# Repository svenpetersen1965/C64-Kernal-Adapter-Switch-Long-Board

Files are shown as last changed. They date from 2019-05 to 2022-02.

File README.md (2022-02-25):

# C64-Kernal-Adapter-Switch-Long-Board
This is a Kernal Adapter/Switch for the Commodore C64 long board prior to ASSY250469. 
The kernal selection can be configured with jumpers, a switch or even with a micro controller. +5V are provided on the pin header 
for this purpose.

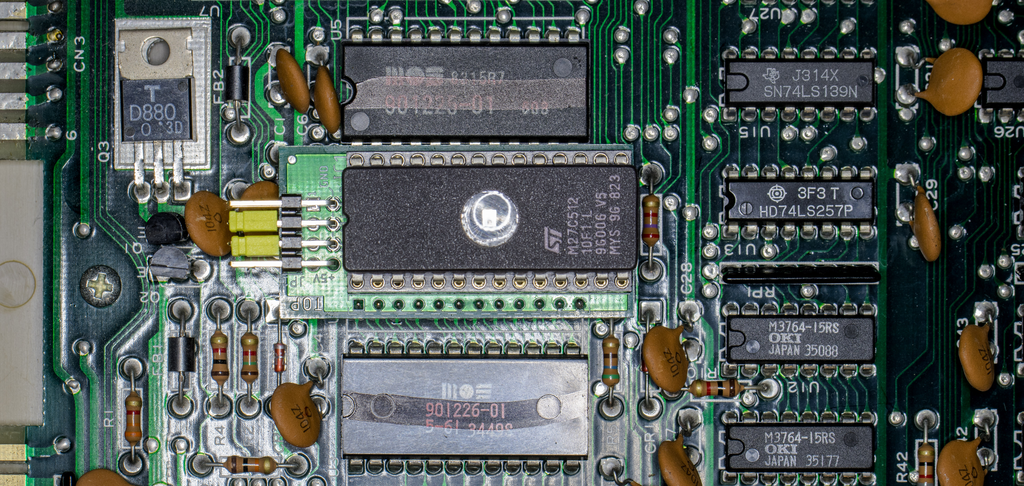
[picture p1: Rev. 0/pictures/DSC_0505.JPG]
C64 kernal adapter/switch for long boards


This adapter is also suitable for the 1541 Floppy Disk ROM.

This development was inspired by Adrian Black's youtube video <a href="https://youtu.be/GPq5xnJRw2w">How-To: C64 Arduino based Restore Key/Four Kernal Switcher/Hard Reset</a>

# Rev. 2
This board revision provides and optional pin header with the address bits A5 and A8 for stereo SID application.

# Calculation of the BOM prices
The component prices of the BOM 0.0 were summed up. The total is 3.81€, which does not include and shipping fees.

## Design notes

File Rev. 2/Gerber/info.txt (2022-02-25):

      
       Board: C64_KernalSw_8k
       Rev.:  2
  
       Files:
       ======
  
       All Gerber files are generated in extended gerber format (RS274X)
       *.TOP        : Film top copper
       *.BOT        :  -"- bottom copper
       *.STC        :  -"- top soldermask 
       *.STS        :  -"- bottom soldermask
       *.PLC        :  -"- silk screen top
       *.PLS        :  -"- silk screen bottom
       *.CRC        :  -"- cream top
       *.DK         : Drills plated Through (Excellon)
       *.NDK        : Drills not plated Through (Excellon)
       *.OUT        : Board outline

       Board Size:
       ===========
       Length     :   45.0 mm
       Width      :   22.0 mm
       Thickness  :   1.6 mm
       Material   :   FR 4
       Copper     :   35 um
       Surface    :   HASL
       
       Remarks:
       ========

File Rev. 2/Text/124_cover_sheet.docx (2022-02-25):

Project Documentation

C64 Kernal Adapter/Switch (Long Board)

Project number: 124

Revision: 2

Date: 14.11.2021

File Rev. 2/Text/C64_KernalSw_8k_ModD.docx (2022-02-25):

C64 Kernal Adapter/Switch (Long Board) Rev. 2

Module Description

# Introduction

The board serves for adapting the KERNAL ROM U4 (type 2364) to a 27C512 (or 27C256, 27C128, 27C64) EPROM. The pin out of both ICs are slightly different and need adaptation. Furthermore, it allows to access (up to 8) different kernals, which can be selected via the pin-header on the module.

This pin-header is connected in a way, that the selection can either be accomplished with standard 2.54mm jumper bridges, DIP-switches, hex-encoding switches or a microcontroller like an Arduino etc.

Signal | Pin | Pin | Signal
A13 | 1 | 2 | GND
A14 | 3 | 4 | GND
A15 | 5 | 6 | GND
+5V | 7 | 8 | +5V

Table 1: Jumper (JP1) for Bank Selection

The +5V pins are to provide supply voltage to a microcontroller.

# Dimensions

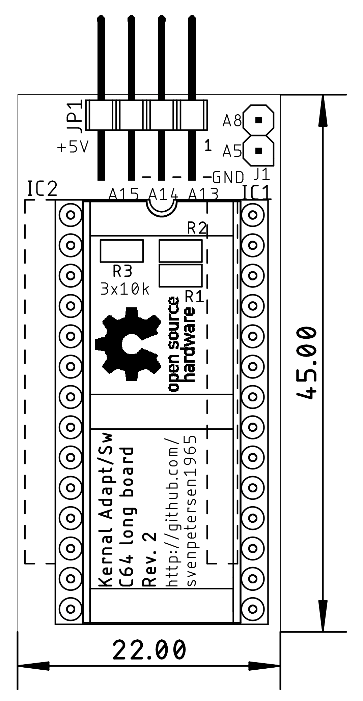
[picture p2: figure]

Figure 1: Kernal Adapter/Switch

# Bank Selection

The desired KERNAL is selected at JP1. For the pinout refer to Table 1. The jumper is installed (vertically) in a way, that it connects the address line with the GND potential.

A15 | A14 | A13 | 8k Block | Addr. Offset
set | set | set | #0 | 0x0000
set | set | open | #1 | 0x2000
set | open | set | #2 | 0x4000
set | open | open | #3 | 0x6000
open | set | set | #4 | 0x8000
open | set | open | #5 | 0xA000
open | open | set | #6 | 0xC000
open | open | open | #7 | 0xE000

Table 2: Selection of EPROM memory blocks

A set jumper corresponds to a LOW level (binary 0), an open jumper to a HIGH level. Do not confuse the C64 memory address and the EPROM memory address. They have the address Bit A0 to A12 in common, but the rest is different. Each of the 8k blocks appears between address $E000 and $FFFF of the C64.

# Sources for KERNAL

The content of the KERNAL ROM can be found here:

http://www.zimmers.net/anonftp/pub/cbm/firmware/computers/c64/index.html (kernal.901227-03.bin (http://www.zimmers.net/anonftp/pub/cbm/firmware/computers/c64/kernal.901227-03.bin))

This file includes the original KERNAL (Rev. 3) and could be loaded to the lowest 8k of the EPROM. In case it is desired to have the original in bank#0. Also Scandinavian KERNAL ROMs can be found at the URL mentioned before or can alternatively be obtained from the Emulator Software VICE (./C64/kernal).

Alternative kernals can be found elsewhere on internet. A reliable source is

https://csdb.dk/

The popular JiffyDOS is still a commercial product and can be acquired for little money from

http://www.go4retro.com/ or

JaffyDOS is a patch for JiffyDOS. The patch program can be obtained from World of Jani:

http://blog.worldofjani.com

# Setting up an EPROM image

Combining the desired ROM (*.bin) files to one programming image works with the software of the programmer. This might a different with different model. Here it is demonstrated using the popular TL866. In case the programmer software does not provide the function, a Hex Editor like HxD will do the job.

The first KERNAL ROM has to be loaded into the buffer like this:

File → Open → Select the BASIC ROM

Use default file load options (Figure 2):

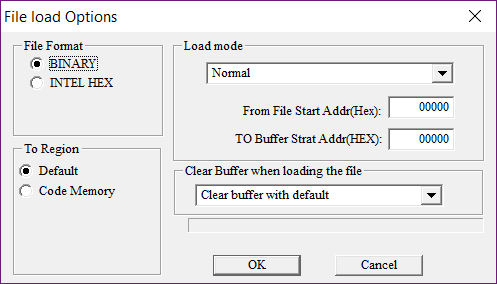
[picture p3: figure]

Figure 2: Default load options, clear buffer with default

Now this Kernal is loaded. It will occupy the addresses 0000 – 1FFF.

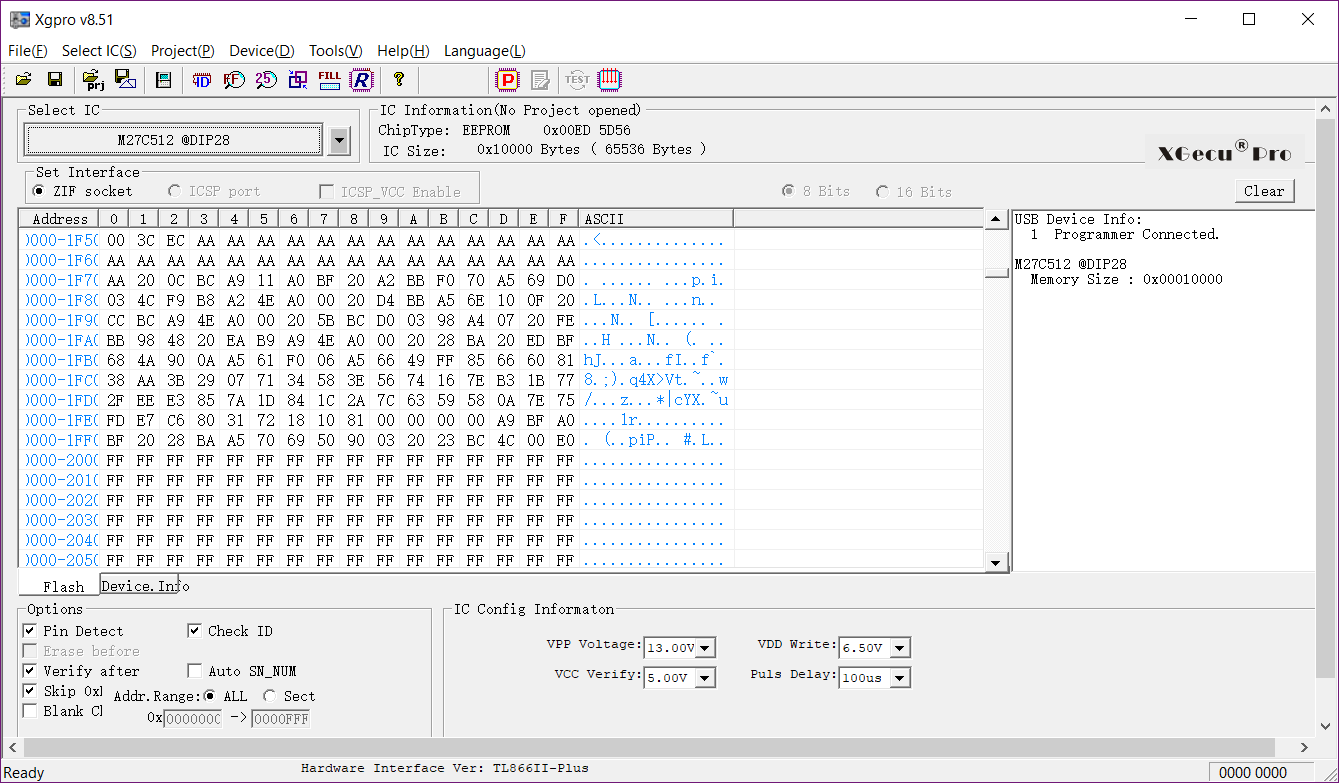
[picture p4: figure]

Figure 3: Buffer content after BASIC was loaded

The buffer above 1FFF is still empty (filled with FF, Figure 3).

The next KERNAL has to be loaded to the next free 8k memory block in the buffer. Please refer to Table 2. Further, it is important, not to clear the buffer. Otherwise, the BASIC will be lost and the EPROM will not work. Refer to Figure 4.

Clear Buffer when loading file is disabled, the address for the first kernal is 2000HEX

Repeat this procedure with the appropriate buffer/EPROM address, until all desired kernals are in the buffer. Store the buffer for later use, insert a blank EPROM and program it. Insert it in the Kernal Adapter/Switch.

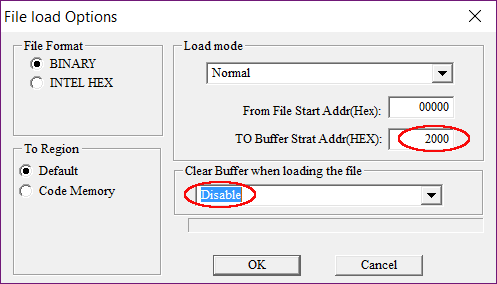
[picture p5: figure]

Figure 4: Load options for the first KERNAL

# Adding more Kernals to an already programmed EPROM

In case the unused 8k memory slots of the EPROM are filled with FF, it is still possible to program additional kernel images without erasing them before. FF is the content of an empty byte in an EPROM. It is possible to alter such a byte to every other byte content. Before the new memory is written, the prior content can be read into the program buffer, then a free 8k slot is determined and the kernel is loaded into that slot. Refer to chapter “Setting up an EPROM image”. Now, the buffer content can be programmed. It is possible to program the complete buffer, the bytes already programmed will (usually) not be corrupted and after programming, the EPROM will verify ok.

# Installation

In some cases, the KERNAL ROM (U4) has to be unsoldered and a socket (preferably round pin precision contacts) has to be installed, before the Kernal Adapter/Switch can be installed on the Long Board. The notch of the EPROM is pointing towards the user port, when installed properly (Figure 5).

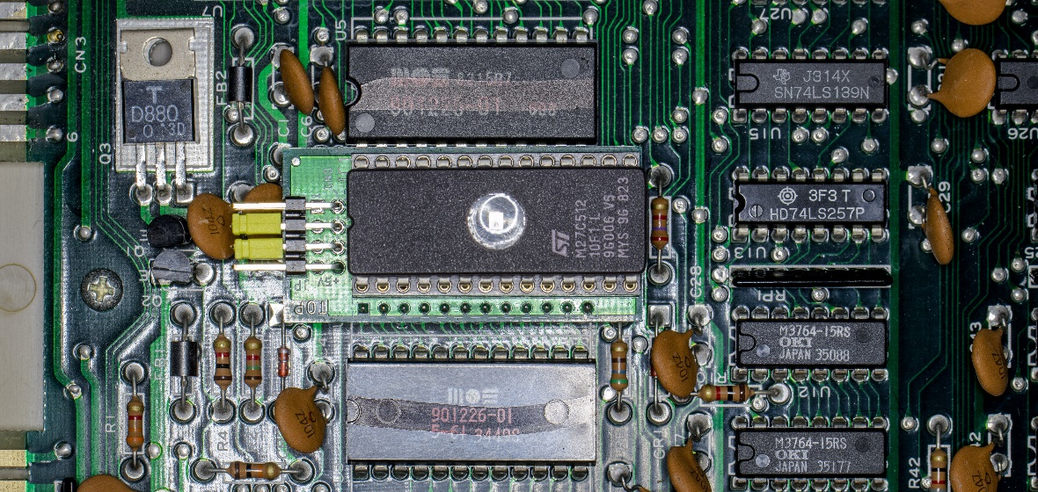
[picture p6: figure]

Figure 5: Installation of the Kernal Adapter/Switch

The capacitor under the board needs to be bent a bit backwards in order not to collide with it.

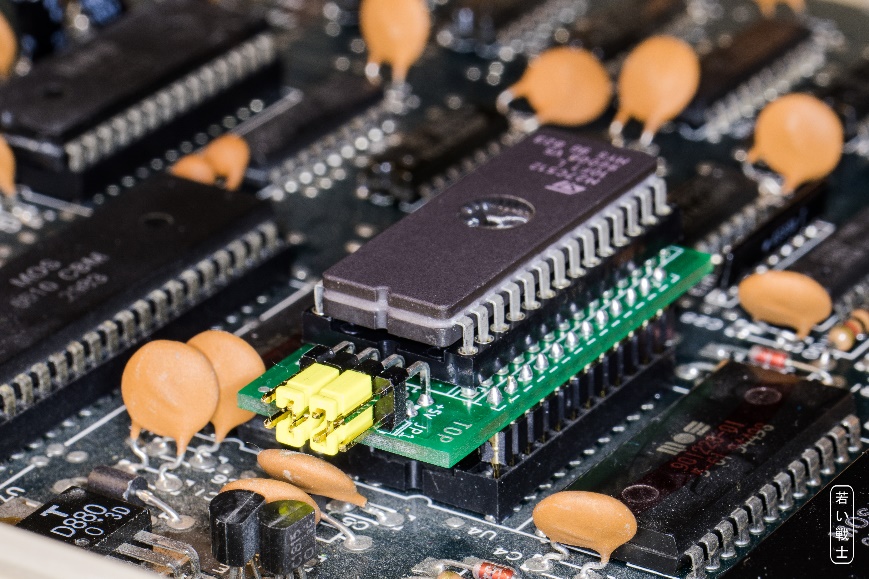
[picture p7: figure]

Figure 6: Parts under the adapter board

# Compatibility of EPROMs

Although a 27C512 type EPROM is recommended, other types of EPROMs can be installed:

EPROM | Size | Capacity
27C64 | 8k | 1x KERNAL
27C128 | 16k | 2x KERNAL
27C256 | 32k | 4x KERNAL
27C512 | 64k | 8x KERNAL

Table 3: Capacity of EPROM types

Those EPROMs are pin compatible, the jumpers, that have no function, due to the size, have to stay open.

EPROM | Size | A15 | A14 | A13
27C512 | 64kx8 | ☑ | ☑ | ☑
27C256 | 32kx8 | open | ☑ | ☑
27C128 | 16kx8 | open | open | ☑
27c64 | 8kx8 | open | open | open

Table 4: Settings per EPROM type

☑: The jumper can be open or closed, depending on the desired selection.

In case Vpp is located at a dedicated pin (pin 1), A15 has no effect anymore. A HIGH level is recommended, the corresponding jumper is open. The /PGM Pin should be set HIGH, this is accomplished by an open jumper for A14. “n.c.” means not connected. Just leave the jumper open for it.

27C64
| 27C128
| | 27C256
| | | 27C512
| | | | SOCKET
Vpp | Vpp | Vpp | A15 | 1 | A15 | VCC | 28 | VCC | VCC | VCC | VCC
A12 | A12 | A12 | A12 | 2 | A12 | A14 | 27 | A14 | A14 | /PGM | /PGM
A7 | A7 | A7 | A7 | 3 | A7 | A13 | 26 | A13 | A13 | A13 | n.c.
A6 | A6 | A6 | A6 | 4 | A6 | A8 | 25 | A8 | A8 | A8 | A8
A5 | A5 | A5 | A5 | 5 | A5 | A9 | 24 | A9 | A9 | A9 | A9
A4 | A4 | A4 | A4 | 6 | A4 | A11 | 23 | A11 | A11 | A11 | A11
A3 | A3 | A3 | A3 | 7 | A3 | /OE | 22 | /G/Vpp | /G | /G | /G
A2 | A2 | A2 | A2 | 8 | A2 | A10 | 21 | A10 | A10 | A10 | A10
A1 | A1 | A1 | A1 | 9 | A1 | GND | 20 | /E | /E | /E | /E
A0 | A0 | A0 | A0 | 10 | A0 | D7 | 19 | D7 | D7 | D7 | D7
D0 | D0 | D0 | D0 | 11 | D0 | D6 | 18 | D6 | D6 | D6 | D6
D1 | D1 | D1 | D1 | 12 | D1 | D5 | 17 | D5 | D5 | D5 | D5
D2 | D2 | D2 | D2 | 13 | D2 | D4 | 16 | D4 | D4 | D4 | D4
GND | GND | GND | GND | 14 | GND | D3 | 15 | D3 | D3 | D3 | D3

Table 5: EPROM pin compatibility

# Startup and Trouble shooting

Before you insert the Kernal Adaptor/Switch into the socket of U4, you should make sure, that there are no fatal failures on it. In the worst case, it will produce a short circuit.

- Check the solder joints on the solder side
- Check the orientation of the socket. The notch is oriented to the side, where the jumper is located
- Make sure, that no jumper is installed horizontally. This could connect GND and VCC, which is a short circuit.
- After inserting the EPROM, check if the notch is at the same side like the notch of the socket. Check all pins are properly seated in the socket and not bent inwards or outwards.

After all these points are correct, nothing really bad can happen to your C64 anymore. If you get a black screen you only have a configuration problem.

- Did you program the EPROM with a proper *.bin file? (*.rom) Maybe check the buffer content of your programmed software again.
- Did you set the address bits A13…A15 correctly? A set (closed) jumper means LOW

# Revision History

## Rev. 0 → Rev. 1

- Solder Pads for the pin header JP1 is ready for solder bridges
- Pin 8 of JP1 is not connected

## Rev. 1 → Rev. 2

- J1 is new and providing A5 and A8 for stereo SID applications

C64_KernalSw_8k_ModD.docx 25.02.2022 09:10 Drafted by Sven Petersen Page 2 of 2 Doc.-No.: 124-6-01-02

C64_KernalSw_8k_ModD.docx 25.02.2022 09:10 Drafted by Sven Petersen Page 1 of 1 Doc.-No.: 124-6-01-01

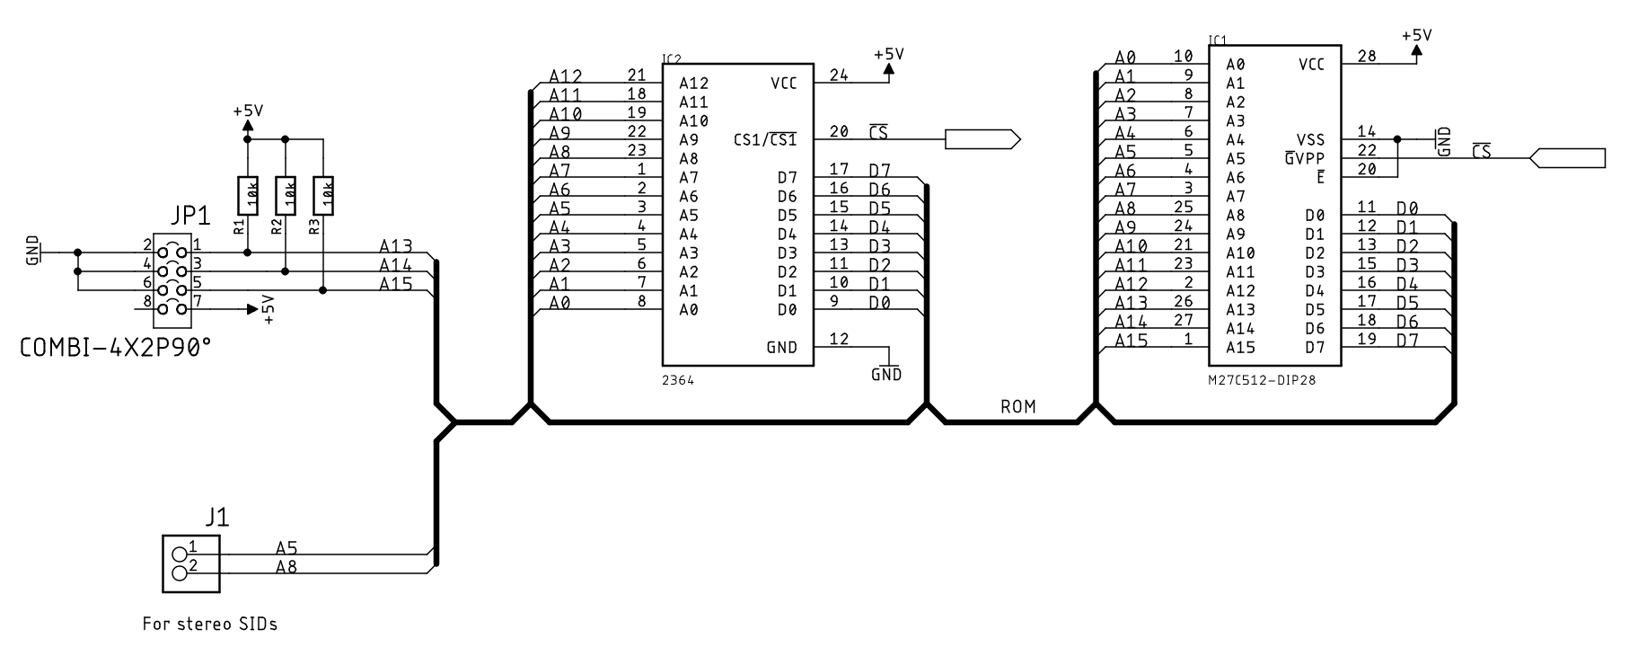
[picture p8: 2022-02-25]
Rev. 2/pictures/C64_KernalSw_8k_v2_sch.png

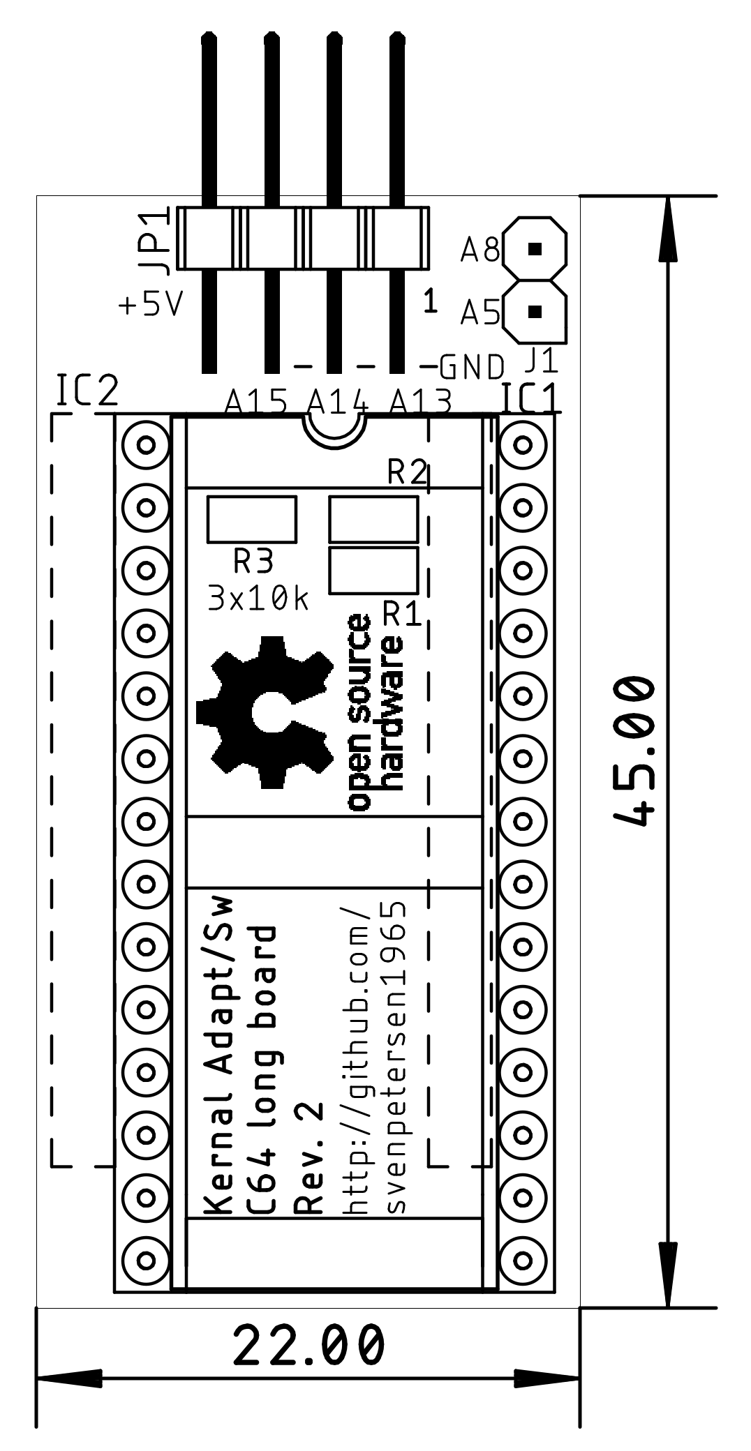
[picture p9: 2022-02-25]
Rev. 2/pictures/C64_KernalSw_8k_v2_dim.png

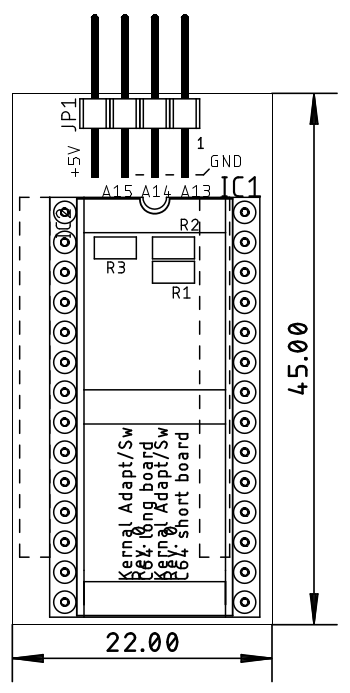
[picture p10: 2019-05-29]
Rev. 1/pictures/C64_KernalSw_8k_v0_dim.png

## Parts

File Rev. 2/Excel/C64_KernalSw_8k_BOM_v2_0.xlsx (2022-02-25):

C64 Kernal Adapter/Switch for lhort boards Rev. 2
Bill of Material Rev. 2.0
Pos. | Qty | Value | Footprint | Ref.-No. | Comment
1 | 1 | 124-2-01-02 | 2 Layer | PCB Rev. 2 | 2 layer, Cu 35µ, HASL, 45mm x 22mm, 1.6mm FR4
2 | 1 | 2x04pin/90° | 2X04_90_SERIES_088 | JP1 | 90° pin header, 2.54mm pitch. E.g. Reichelt MPE 088-2-008
3 | 3 | Jumper | 2.54mm | (JP1) | Jumpers for address selection (in case it is intended to jumper the kenal selection)
4 | 3 | 10k | 0805 | R1, R2, R3 | SMD resistor
5 | 1 | two Pinstrip, precision round pins, cut to 12 pins length | DIL24_SOCKET | IC2 | Precision Round pins mandatory! E.g. Reichelt BKL 10120540 or
 |  |  |  |  | 10PCS Single Row 40Pin 2.54mm Round Male Pin Header machined (https://www.ebay.de/itm/10PCS-Single-Row-40Pin-2-54mm-Round-Male-Pin-Header-machined/281821698031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)
6 | 1 | M27C512 | DIL28-6 | IC1 | EPROM 200ns or faster recommended, alternative sizes: 27C64, 27C128, 27C256 possible
7 | 1 | DIP28 socket | DIL28-6 | (IC1) | Precision round pin is recommended
8 | 1 | Pin header 2p, 2.54mm |  | J1 | standard pin header

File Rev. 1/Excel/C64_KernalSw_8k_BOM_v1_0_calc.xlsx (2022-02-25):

C64 Kernal Adapter/Switch for Short boards Rev. 1
Bill of Material Rev. 1.0
Pos. | Qty | Value | €/ea | € | Comment
1 | 1 | 124-2-01-01 | 1.00 € | 1.00 € | 2 layer, Cu 35µ, HASL, 45mm x 22mm, 1.6mm FR4
2 | 1 | 2x04pin/90° | 0.27 € | 0.27 € | 90° pin header, 2.54mm pitch. E.g. Reichelt MPE 088-2-008
3 | 3 | Jumper | 0.02 € | 0.06 € | Jumpers for address selection (in case it is intended to jumper the kenal selection)
4 | 3 | 10k | 0.02 € | 0.06 € | SMD resistor
5 | 1 | two Pinstrip, precision round pins, cut to 12 pins length | 1.99 € | 1.99 € | Precision Round pins mandatory! E.g. Reichelt BKL 10120540 or
 |  |  |  | 0.00 € | 10PCS Single Row 40Pin 2.54mm Round Male Pin Header machined (https://www.ebay.de/itm/10PCS-Single-Row-40Pin-2-54mm-Round-Male-Pin-Header-machined/281821698031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)
6 | 1 | M27C512 | 0.00 € | 0.00 € | EPROM 200ns or faster recommended, alternative sizes: 27C64, 27C128, 27C256 possible
7 | 1 | DIP28 socket | 0.43 € | 0.43 € | Precision round pin is recommended
8 |  |  | Total | 3.81 €

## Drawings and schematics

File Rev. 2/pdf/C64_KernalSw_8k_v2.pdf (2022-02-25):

# Project Documentation

## C64 Kernal Adapter/Switch (Long Board)

## Project number: 124

## Revision: 2

## Date: 14.11.2021

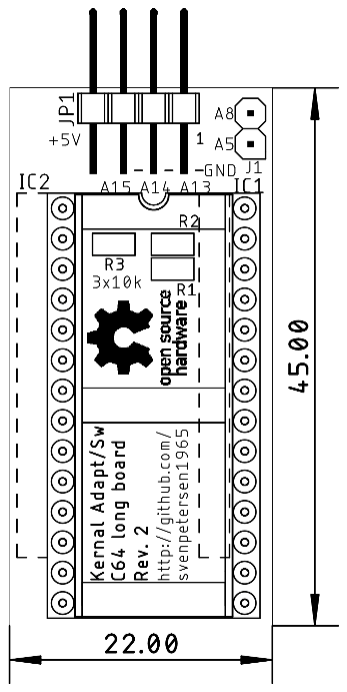
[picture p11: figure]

C64_KernalSw_8k_ModD.docx | | 25.02.2022 09:10
Drafted by Sven Petersen | Page 1 of 6 | Doc.-No.: 124-6-01-02

### C64 Kernal Adapter/Switch (Long Board) Rev. 2

### Module Description

## Introduction

The board serves for adapting the KERNAL ROM U4 (type 2364) to a 27C512 (or 27C256, 27C128, 27C64) EPROM. The pin out of both ICs are slightly different and need adaptation. Furthermore, it allows to access (up to 8) different kernals, which can be selected via the pin-header on the module.

This pin-header is connected in a way, that the selection can either be accomplished with standard 2.54mm jumper bridges, DIP-switches, hex-encoding switches or a microcontroller like an Arduino etc.

Signal Pin | Pin Signal
A13 | 1 | 2 | GND
A14 | 3 | 4 | GND
A15 | 5 | 6 | GND
+5V | 7 | 8 | +5V
Table 1: Jumper (JP1) for Bank Selection

The +5V pins are to provide supply voltage to a microcontroller.

## Dimensions

Figure 1: Kernal Adapter/Switch

## Bank Selection

The desired KERNAL is selected at JP1. For the pinout refer to Table 1. The jumper is installed (vertically) in a way, that it connects the address line with the GND potential.

C64_KernalSw_8k_ModD.docx | | 25.02.2022 09:10
Drafted by Sven Petersen | Page 2 of 6 | Doc.-No.: 124-6-01-02
A15 | A14 | A13 | 8k Block | Addr. Offset
set | set | set | #0 | 0x0000
set | set | open | #1 | 0x2000
set | open | set | #2 | 0x4000
set | open | open | #3 | 0x6000
open | set | set | #4 | 0x8000
open | set | open | #5 | 0xA000
open | open | set | #6 | 0xC000
open | open | open | #7 | 0xE000
Table 2: Selection of EPROM memory blocks

A set jumper corresponds to a LOW level (binary 0), an open jumper to a HIGH level. Do not confuse the C64 memory address and the EPROM memory address. They have the address Bit A0 to A12 in common, but the rest is different. Each of the 8k blocks appears between address $E000 and $FFFF of the C64.

## Sources for KERNAL

The content of the KERNAL ROM can be found here:

http://www.zimmers.net/anonftp/pub/cbm/firmware/computers/c64/index.html (kernal.901227-03.bin) (http://www.zimmers.net/anonftp/pub/cbm/firmware/computers/c64/kernal.901227-03.bin)

This file includes the original KERNAL (Rev. 3) and could be loaded to the lowest 8k of the EPROM. In case it is desired to have the original in bank#0. Also Scandinavian KERNAL ROMs can be found at the URL mentioned before or can alternatively be obtained from the Emulator Software VICE (./C64/kernal).

Alternative kernals can be found elsewhere on internet. A reliable source is

https://csdb.dk/

The popular JiffyDOS is still a commercial product and can be acquired for little money from

http://www.go4retro.com/ or

JaffyDOS is a patch for JiffyDOS. The patch program can be obtained from World of Jani:

http://blog.worldofjani.com

## Setting up an EPROM image

Combining the desired ROM (*.bin) files to one programming image works with the software of the programmer. This might a different with different model. Here it is demonstrated using the popular TL866. In case the programmer software does not provide the function, a Hex Editor like HxD will do the job.

The first KERNAL ROM has to be loaded into the buffer like this:

File → Open → Select the BASIC ROM

Use default file load options (Figure 2):

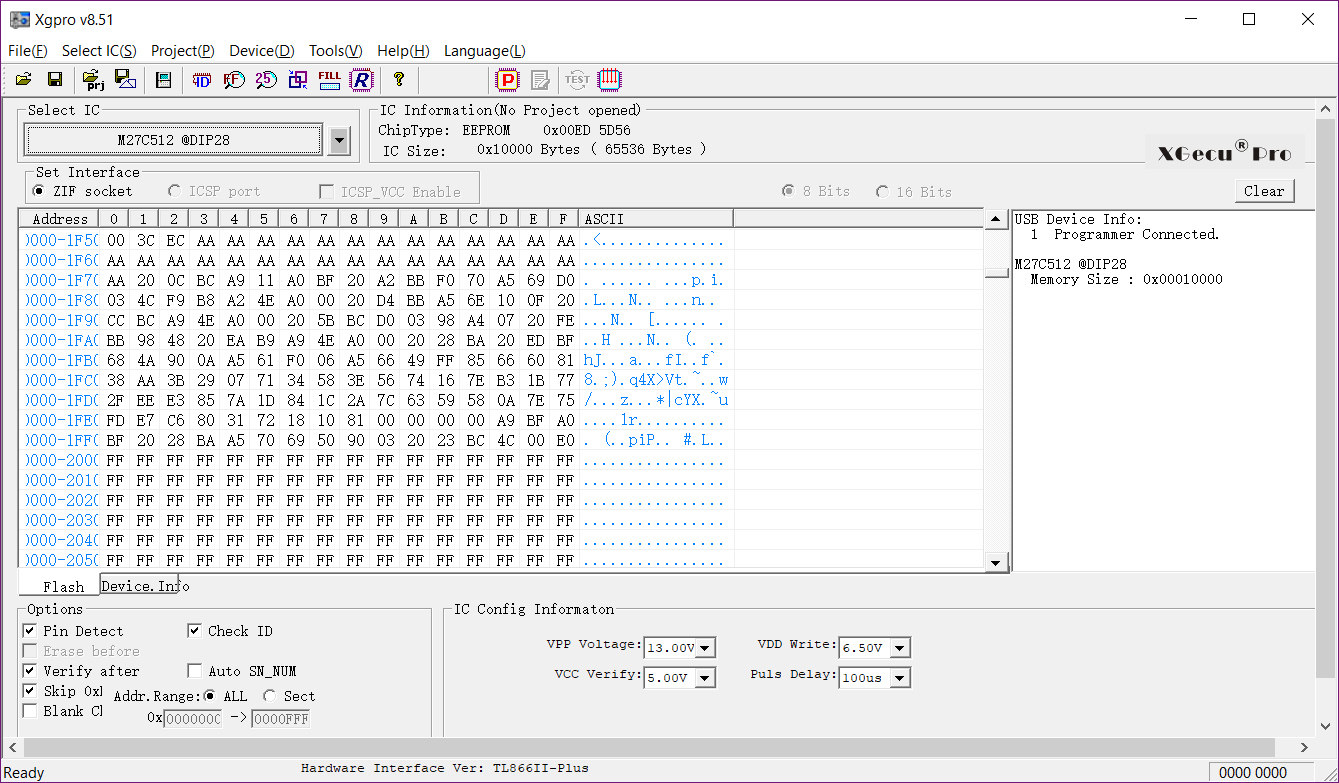
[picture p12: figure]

C64_KernalSw_8k_ModD.docx | | 25.02.2022 09:10
Drafted by Sven Petersen | Page 3 of 6 | Doc.-No.: 124-6-01-02

Figure 2: Default load options, clear buffer with default
Now this Kernal is loaded. It will occupy the addresses 0000 – 1FFF.

Figure 3: Buffer content after BASIC was loaded

The buffer above 1FFF is still empty (filled with FF, Figure 3).

The next KERNAL has to be loaded to the next free 8k memory block in the buffer. Please refer to Table 2. Further, it is important, not to clear the buffer. Otherwise, the BASIC will be lost and the EPROM will not work. Refer to Figure 4.

Clear Buffer when loading file is disabled, the address for the first kernal is 2000HEX

Repeat this procedure with the appropriate buffer/EPROM address, until all desired kernals are in the buffer. Store the buffer for later use, insert a blank EPROM and program it. Insert it in the Kernal Adapter/Switch.

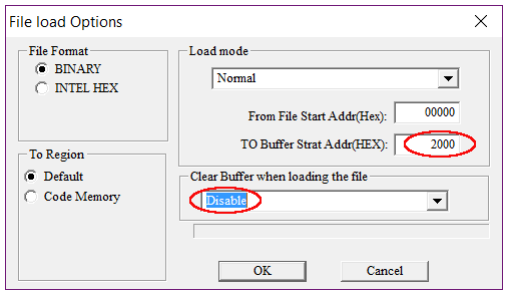
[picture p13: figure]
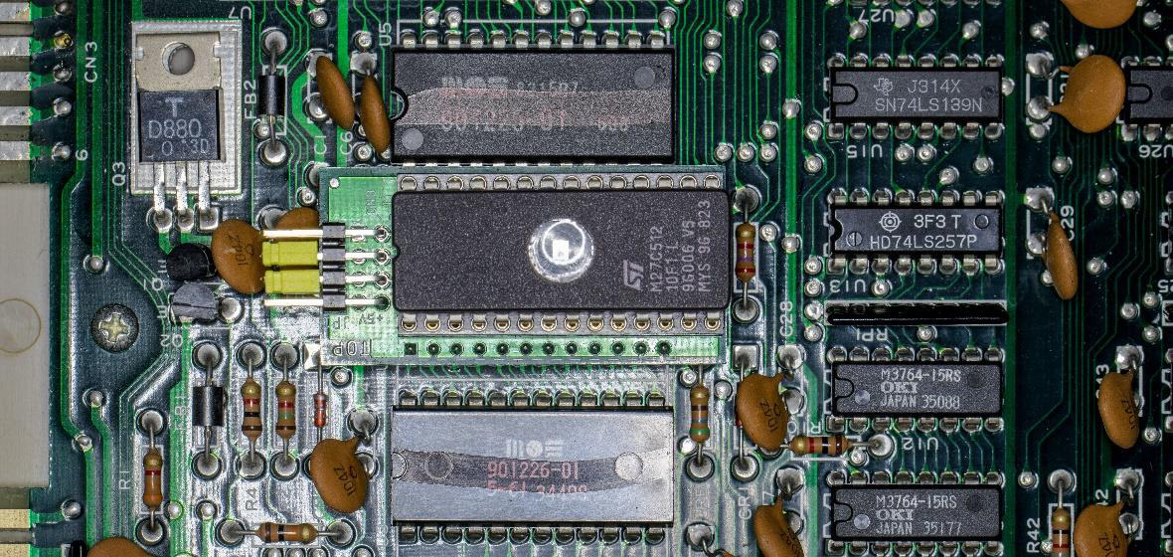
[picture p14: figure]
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

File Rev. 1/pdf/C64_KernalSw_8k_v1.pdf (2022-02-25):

# Project Documentation

## C64 Kernal Adapter/Switch (Long Board)

## Project number: 124

## Revision: 1

## Date: 17.02.2021

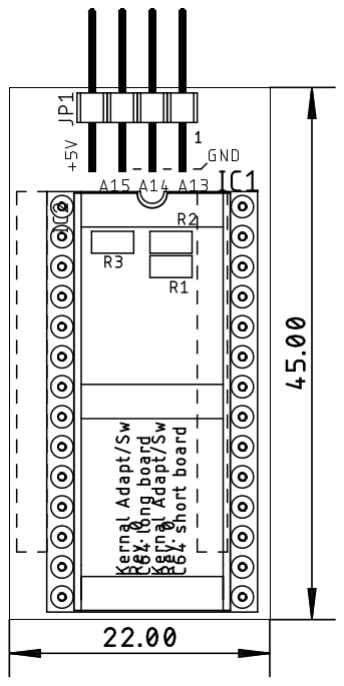
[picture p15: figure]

C64_KernalSw_8k_ModD.docx | | 25.02.2022 08:42
Drafted by Sven Petersen | Page 1 of 6 | Doc.-No.: 124-6-01-01

### C64 Kernal Adapter/Switch (Long Board) Rev. 1

### Module Description

## Introduction

The board serves for adapting the KERNAL ROM U4 (type 2364) to a 27C512 (or 27C256, 27C128, 27C64) EPROM. The pin out of both ICs are slightly different and need adaptation. Furthermore, it allows to access (up to 8) different kernals, which can be selected via the pin-header on the module.

This pin-header is connected in a way, that the selection can either be accomplished with standard 2.54mm jumper bridges, DIP-switches, hex-encoding switches or a microcontroller like an Arduino etc.

Signal Pin | Pin Signal
A13 | 1 | 2 | GND
A14 | 3 | 4 | GND
A15 | 5 | 6 | GND
+5V | 7 | 8 | +5V
Table 1: Jumper (JP1) for Bank Selection

The +5V pins are to provide supply voltage to a microcontroller.

## Dimensions

Figure 1: Kernal Adapter/Switch

## Bank Selection

The desired KERNAL is selected at JP1. For the pinout refer to Table 1. The jumper is installed (vertically) in a way, that it connects the address line with the GND potential.

C64_KernalSw_8k_ModD.docx | | 25.02.2022 08:42
Drafted by Sven Petersen | Page 2 of 6 | Doc.-No.: 124-6-01-01
A15 | A14 | A13 | 8k Block | Addr. Offset
set | set | set | #0 | 0x0000
set | set | open | #1 | 0x2000
set | open | set | #2 | 0x4000
set | open | open | #3 | 0x6000
open | set | set | #4 | 0x8000
open | set | open | #5 | 0xA000
open | open | set | #6 | 0xC000
open | open | open | #7 | 0xE000
Table 2: Selection of EPROM memory blocks

A set jumper corresponds to a LOW level (binary 0), an open jumper to a HIGH level. Do not confuse the C64 memory address and the EPROM memory address. They have the address Bit A0 to A12 in common, but the rest is different. Each of the 8k blocks appears between address $E000 and $FFFF of the C64.

## Sources for KERNAL

The content of the KERNAL ROM can be found here:

http://www.zimmers.net/anonftp/pub/cbm/firmware/computers/c64/index.html (kernal.901227-03.bin) (http://www.zimmers.net/anonftp/pub/cbm/firmware/computers/c64/kernal.901227-03.bin)

This file includes the original KERNAL (Rev. 3) and could be loaded to the lowest 8k of the EPROM. In case it is desired to have the original in bank#0. Also Scandinavian KERNAL ROMs can be found at the URL mentioned before or can alternatively be obtained from the Emulator Software VICE (./C64/kernal).

Alternative kernals can be found elsewhere on internet. A reliable source is

https://csdb.dk/

The popular JiffyDOS is still a commercial product and can be acquired for little money from

http://www.go4retro.com/ or

JaffyDOS is a patch for JiffyDOS. The patch program can be obtained from World of Jani:

http://blog.worldofjani.com

## Setting up an EPROM image

Combining the desired ROM (*.bin) files to one programming image works with the software of the programmer. This might a different with different model. Here it is demonstrated using the popular TL866. In case the programmer software does not provide the function, a Hex Editor like HxD will do the job.

The first KERNAL ROM has to be loaded into the buffer like this:

File → Open → Select the BASIC ROM

Use default file load options (Figure 2):


C64_KernalSw_8k_ModD.docx | | 25.02.2022 08:42
Drafted by Sven Petersen | Page 3 of 6 | Doc.-No.: 124-6-01-01

Figure 2: Default load options, clear buffer with default
Now this Kernal is loaded. It will occupy the addresses 0000 – 1FFF.

Figure 3: Buffer content after BASIC was loaded

The buffer above 1FFF is still empty (filled with FF, Figure 3).

The next KERNAL has to be loaded to the next free 8k memory block in the buffer. Please refer to Table 2. Further, it is important, not to clear the buffer. Otherwise, the BASIC will be lost and the EPROM will not work. Refer to Figure 4.

Clear Buffer when loading file is disabled, the address for the first kernal is 2000HEX

Repeat this procedure with the appropriate buffer/EPROM address, until all desired kernals are in the buffer. Store the buffer for later use, insert a blank EPROM and program it. Insert it in the Kernal Adapter/Switch.

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

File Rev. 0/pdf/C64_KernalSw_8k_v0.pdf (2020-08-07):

# Project Documentation

## C64 Kernal Adapter/Switch (Long Board)

## Project number: 124

## Revision: 0

## Date: 05.05.2019


C64_KernalSw_8k_ModD.docx | | 29.05.2019 11:34
Drafted by Sven Petersen | Page 1 of 6 | Doc.-No.: 124-6-01-00

### C64 Kernal Adapter/Switch (Long Board) Rev. 0

### Module Description

## Introduction

The board serves for adapting the KERNAL ROM U4 (type 2364) to a 27C512 (or 27C256, 27C128, 27C64) EPROM. The pin out of both ICs are slightly different and need adaptation. Furthermore, it allows to access (up to 8) different kernals, which can be selected via the pin-header on the module.

This pin-header is connected in a way, that the selection can either be accomplished with standard 2.54mm jumper bridges, DIP-switches, hex-encoding switches or a microcontroller like an Arduino etc.

Signal Pin | Pin Signal
A13 | 1 | 2 | GND
A14 | 3 | 4 | GND
A15 | 5 | 6 | GND
+5V | 7 | 8 | +5V
Table 1: Jumper (JP1) for Bank Selection

The +5V pins are to provide supply voltage to a microcontroller.

## Dimensions

Figure 1: Kernal Adapter/Switch

## Bank Selection

The desired KERNAL is selected at JP1. For the pinout refer to Table 1. The jumper is installed (vertically) in a way, that it connects the address line with the GND potential.

C64_KernalSw_8k_ModD.docx | | 29.05.2019 11:34
Drafted by Sven Petersen | Page 2 of 6 | Doc.-No.: 124-6-01-00
A15 | A14 | A13 | 8k Block | Addr. Offset
set | set | set | #0 | 0x0000
set | set | open | #1 | 0x2000
set | open | set | #2 | 0x4000
set | open | open | #3 | 0x6000
open | set | set | #4 | 0x8000
open | set | open | #5 | 0xA000
open | open | set | #6 | 0xC000
open | open | open | #7 | 0xE000
Table 2: Selection of EPROM memory blocks

A set jumper corresponds to a LOW level (binary 0), an open jumper to a HIGH level. Do not confuse the C64 memory address and the EPROM memory address. They have the address Bit A0 to A12 in common, but the rest is different. Each of the 8k blocks appears between address $E000 and $FFFF of the C64.

## Sources for KERNAL

The content of the KERNAL ROM can be found here:

http://www.zimmers.net/anonftp/pub/cbm/firmware/computers/c64/index.html (kernal.901227-03.bin) (http://www.zimmers.net/anonftp/pub/cbm/firmware/computers/c64/kernal.901227-03.bin)

This file includes the original KERNAL (Rev. 3) and could be loaded to the lowest 8k of the EPROM. In case it is desired to have the original in bank#0. Also Scandinavian KERNAL ROMs can be found at the URL mentioned before or can alternatively be obtained from the Emulator Software VICE (./C64/kernal).

Alternative kernals can be found elsewhere on internet. A reliable source is

https://csdb.dk/

The popular JiffyDOS is still a commercial product and can be acquired for little money from

http://www.go4retro.com/ or

JaffyDOS is a patch for JiffyDOS. The patch program can be obtained from World of Jani:

http://blog.worldofjani.com

## Setting up an EPROM image

Combining the desired ROM (*.bin) files to one programming image works with the software of the programmer. This might a different with different model. Here it is demonstrated using the popular TL866. In case the programmer software does not provide the function, a Hex Editor like HxD will do the job.

The first KERNAL ROM has to be loaded into the buffer like this:

File → Open → Select the BASIC ROM

Use default file load options (Figure 2):

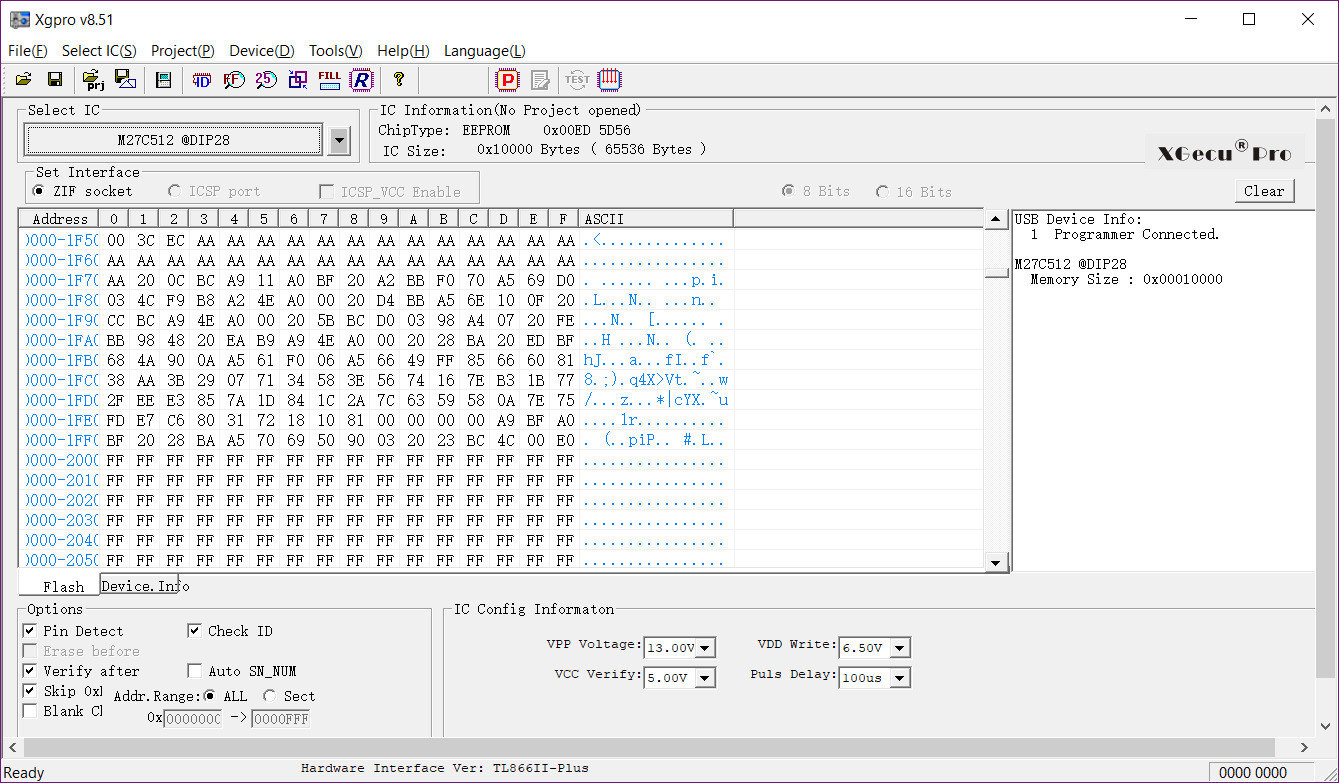
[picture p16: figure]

C64_KernalSw_8k_ModD.docx | | 29.05.2019 11:34
Drafted by Sven Petersen | Page 3 of 6 | Doc.-No.: 124-6-01-00

Figure 2: Default load options, clear buffer with default
Now this Kernal is loaded. It will occupy the addresses 0000 – 1FFF.

Figure 3: Buffer content after BASIC was loaded

The buffer above 1FFF is still empty (filled with FF, Figure 3).

The next KERNAL has to be loaded to the next free 8k memory block in the buffer. Please refer to Table 2. Further, it is important, not to clear the buffer. Otherwise, the BASIC will be lost and the EPROM will not work. Refer to Figure 4.

Clear Buffer when loading file is disabled, the address for the first kernal is 2000HEX

Repeat this procedure with the appropriate buffer/EPROM address, until all desired kernals are in the buffer. Store the buffer for later use, insert a blank EPROM and program it. Insert it in the Kernal Adapter/Switch.

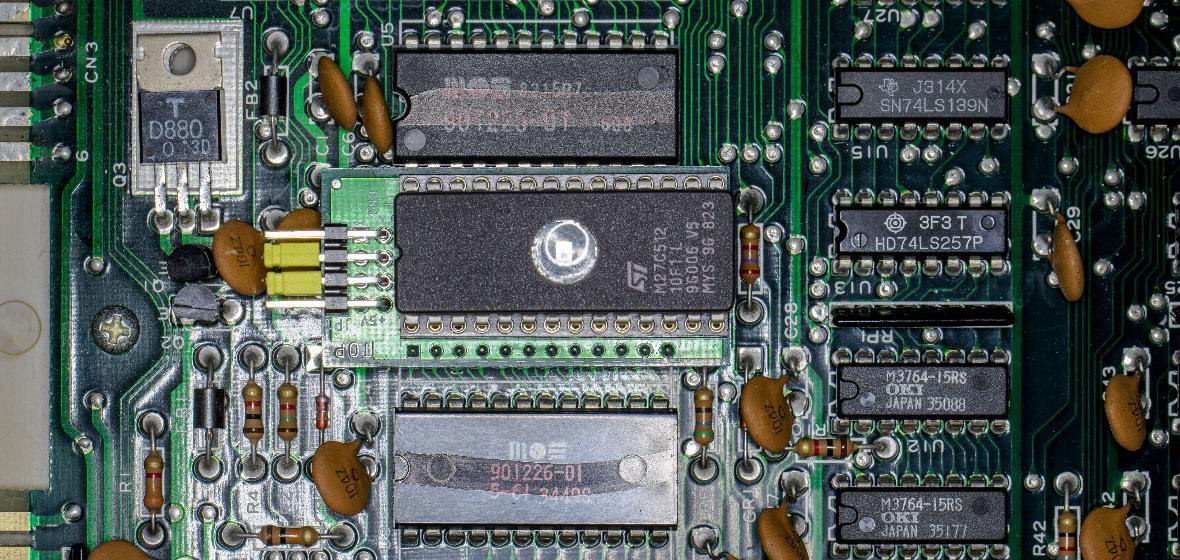
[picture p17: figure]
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

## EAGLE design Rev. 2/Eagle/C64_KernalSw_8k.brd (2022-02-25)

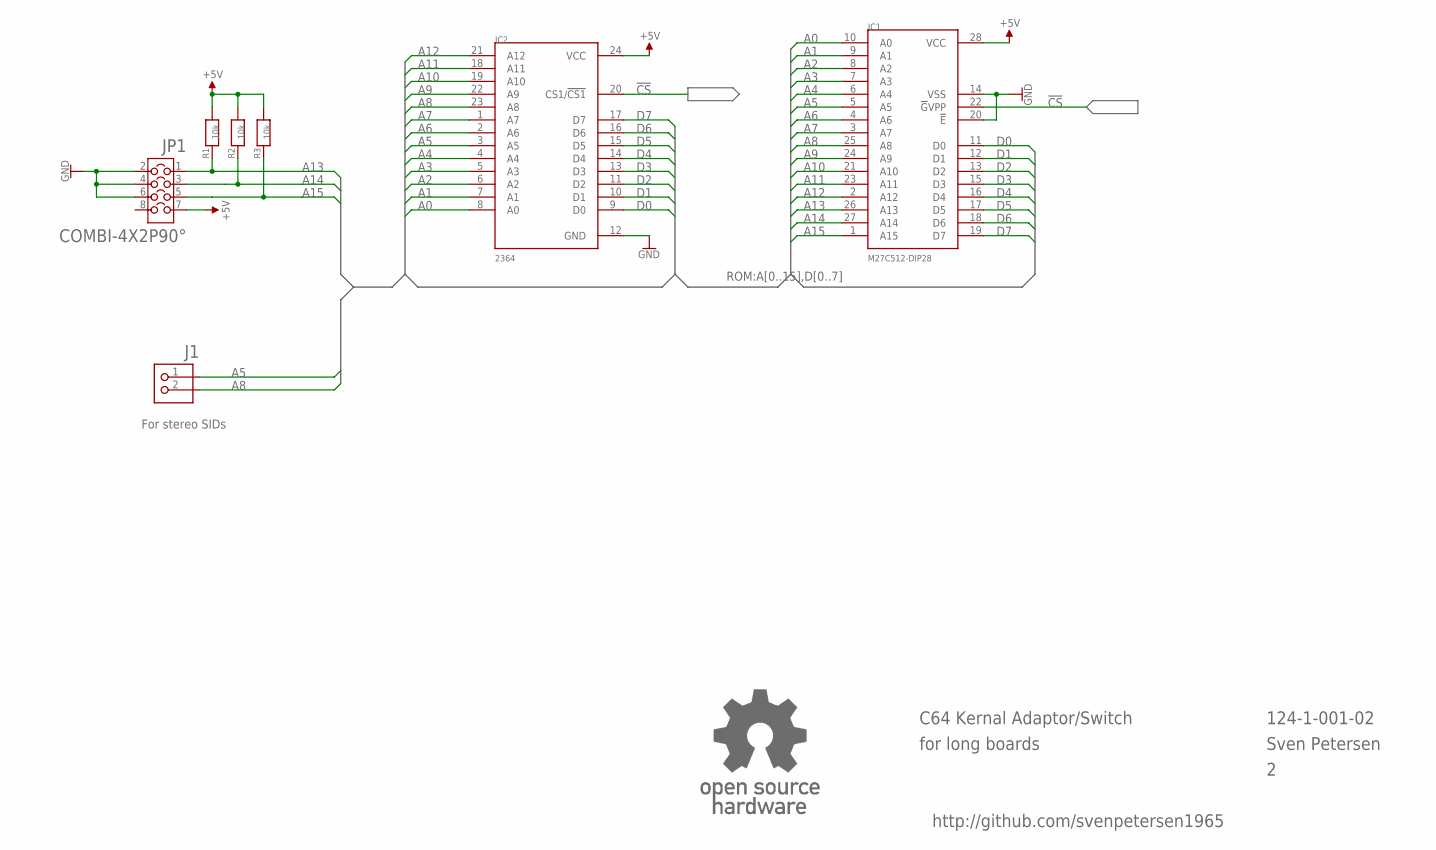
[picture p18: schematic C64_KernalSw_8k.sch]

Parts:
IC1: M27C512-DIP28; DIL28-6
IC2: 2364; DIL24_SOCKET
J1: PINHD-1X2; 1X02
JP1: COMBI-4X2P90°; COMBI-4X2-90
R1, R2, R3: 10k; 0805
U$11: OPEN_SOURCE_HW; OPENHW

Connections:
!CS: IC1.22 (!G!VPP), IC2.20 (CS1/!CS1)
+5V: IC1.28 (VCC), IC2.24 (VCC), JP1.7, R1.2, R2.2, R3.2
A0: IC1.10 (A0), IC2.8 (A0)
A1: IC1.9 (A1), IC2.7 (A1)
A2: IC1.8 (A2), IC2.6 (A2)
A3: IC1.7 (A3), IC2.5 (A3)
A4: IC1.6 (A4), IC2.4 (A4)
A5: IC1.5 (A5), IC2.3 (A5), J1.1
A6: IC1.4 (A6), IC2.2 (A6)
A7: IC1.3 (A7), IC2.1 (A7)
A8: IC1.25 (A8), IC2.23 (A8), J1.2
A9: IC1.24 (A9), IC2.22 (A9)
A10: IC1.21 (A10), IC2.19 (A10)
A11: IC1.23 (A11), IC2.18 (A11)
A12: IC1.2 (A12), IC2.21 (A12)
A13: IC1.26 (A13), JP1.1, R1.1
A14: IC1.27 (A14), JP1.3, R2.1
A15: IC1.1 (A15), JP1.5, R3.1
D0: IC1.11 (D0), IC2.9 (D0)
D1: IC1.12 (D1), IC2.10 (D1)
D2: IC1.13 (D2), IC2.11 (D2)
D3: IC1.15 (D3), IC2.13 (D3)
D4: IC1.16 (D4), IC2.14 (D4)
D5: IC1.17 (D5), IC2.15 (D5)
D6: IC1.18 (D6), IC2.16 (D6)
D7: IC1.19 (D7), IC2.17 (D7)
GND: IC1.14 (VSS), IC1.20 (!E), IC2.12 (GND), JP1.2, JP1.4, JP1.6

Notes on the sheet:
124-1-001-02
Sven Petersen
C64 Kernal Adaptor/Switch
for long boards
http://github.com/svenpetersen1965
For stereo SIDs

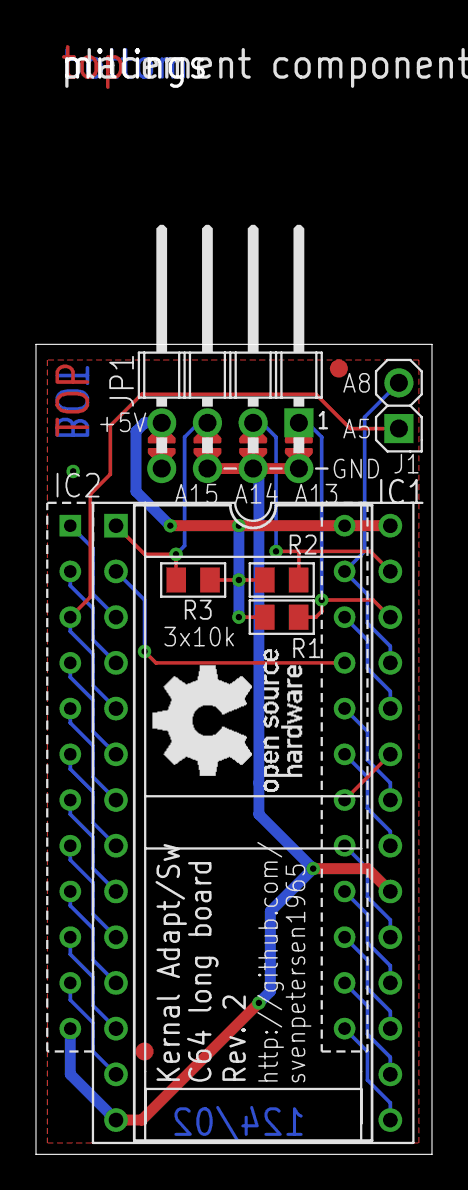
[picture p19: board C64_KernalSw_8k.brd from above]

Board: 2 copper layers, 22.0 x 45.0 mm, 14 parts (1 on the bottom side), 27 nets.

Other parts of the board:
U$6: SVEN_TAG
U$16: GS28P
U$17, U$18: SMD_REF_R1MM
U$19: 2LAYER
U$20: PCB-TITLE/

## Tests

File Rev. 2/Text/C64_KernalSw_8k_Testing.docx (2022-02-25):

C64 Kernal Adapter/Switch (Long Board) Rev. 2

Testing

A further testing of Rev. 2 is not required since the changes are marginal. The PCB is in daily use without any problems. The following tests were conducted with Rev. 0.

An image file for programming an EPROM was set up.

8k Block | Addr. Offset | Firmware
#0 | 0x0000 | Original Kernal

#1 | 0x2000 | JiffyDOS

#2 | 0x4000 | JaffyDOS

#3 | 0x6000 | ExOS v3

#4 | 0x8000 | SpeedDos

#5 | 0xA000 | DolphinDos

#6 | 0xC000 | TurboTape

#7 | 0xE000 | Modified Original Kernal

Table 1: Firmware Setup

A M27C512 EPROM (ST, 100ns) was programmed using a XGecu TL866 II Plus programmer.

The EPROM was inserted into the module, the module was installed in the socket of U4 (KERNAL) on an ASSY250407 Rev. B mainboard.

The jumper configured: A15 set, A14 set, A13 set.

The C64 was switched on. The commodore kernal booted, different software was loaded and executed: everything seems to be working.

The jumper setting was modified to start one alternative kernal after the other. The kernal all booted and a variety of software loaded and executed without problems.

Finally, the jumpers were configured for JiffyDOS and the C64 was used for a couple of days without any problem.

Since the pin compatibility with other EPROMs (27C256, 27C128, 27C64) is widely proved, it is assumed, that this kernal adapter works with them as well.

Conclusion: The C64 Kernal Adapter/switch is fully functional.

C64_KernalSw_8k_Testing.docx 25.02.2022 09:12 Drafted by Sven Petersen Page 2 of 2 Doc.-No.: 000-6-00-00

C64_KernalSw_8k_Testing.docx 25.02.2022 09:12 Drafted by Sven Petersen Page 1 of 1 Doc.-No.: 124-6-02-02

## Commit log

2020-06-09 BOM calculation added
    [C64_KernalSw_8k_BOM_v0_0_calc.xlsx]
2020-08-07 Silk Screen Update
    [C64_KernalSw_8k.brd, C64_KernalSw_8k.sch]
2022-02-25 Rev. 1 released
    [C64_KernalSw_8k.brd, C64_KernalSw_8k.sch, C64_KernalSw_8k_BOM_v1_0.xlsx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]
2022-02-25 Rev. 2 released
    [C64_KernalSw_8k.brd, C64_KernalSw_8k.sch, C64_KernalSw_8k_BOM_v2_0.xlsx]
